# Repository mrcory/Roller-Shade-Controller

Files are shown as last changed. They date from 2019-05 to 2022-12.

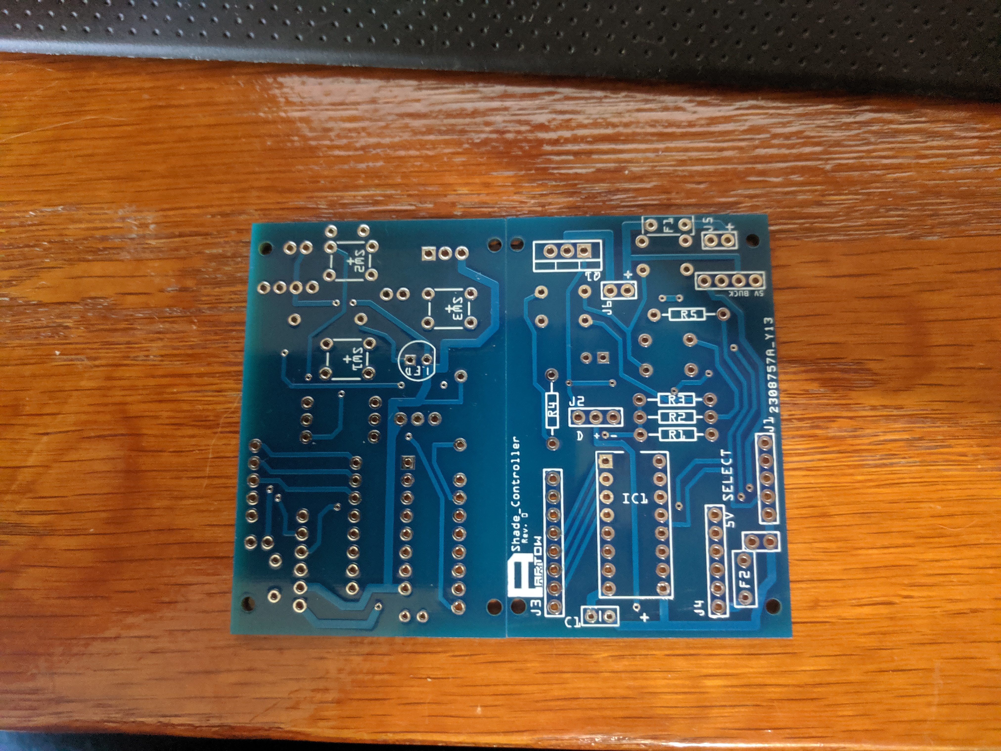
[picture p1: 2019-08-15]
Extra_Resources/Part Images/IMG_20190808_134944.jpg

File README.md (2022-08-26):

# Roller-Shade-Controller
D1 Mini powered roller shade controller for my 3D printed roller shade.

Intended for use with a custom PCB I designed, but can also be used with a custome protoboard. (As I did during testing.)

## Welcome to my little project!
The purpose behind this project was two-fold. One, I want a remote controlled shade for my window, but didn't want to spend that much. Two, I wanted a small project to do to break the tedium of my working on my aquarium controller.

I have succeeded in both of those goals. (If I do say so myself.) I managed to build the majority of the hardware for the shade for under $20 unit cost estimated. (I did luck out on cheap motors) and Unfortunately, this does not include beautification. Function on the other hand has been a success. (Who says you need form with function.)

More features, like physical button control, will add a little bit to the cost but aren't strictly necessary.

## Project Info

## Setup
[Check The Wiki](https://github.com/mrcory/Roller-Shade-Controller/wiki)

### Hardware
 [Thingiverse Models](https://www.thingiverse.com/thing:3628982) are now available.
 
 Motion is driven by a 28BYJ-48 with a ULN2003.

 Currently controlled by a Lolin NodeMCU v3, but it will be replaced by a Wemos D1 Mini

 A donor roller shade.

 1/2" EMT conduit.

### Software
* Blynk is used as a remote control for this project.

* Home Assistant is supported via [home-assistant-integration](https://github.com/dawidchyrzynski/arduino-home-assistant/blob/main/examples/fan/fan.ino).

* [AccelStepper (Fork)](https://github.com/waspinator/AccelStepper) is used to actually drive the motor. _(This version is available in the library manager.)_

* [CmdArduino](https://github.com/fakufaku/CmdArduino) is used for control of serial monitor. (A little library I really like.)

* FastLED is used to control addressable LEDs.  

* WiFiManager as an option to configure WiFi. (>2.7.0)

### Goal
The goal is to make a low cost remote controlled roller shade that can be made DIY. The only tools needed are some hex wrenches, a hacksaw (band saw is also acceptable), and a 3D printer.

More tools may be required to make the final product look nice, but that is _optional_.

## Known Issues
* Due to the way that the stepper is driven Blynk will disconnect when the shade is traveling. This is because Blynk slows the code execution. I believe this is happening due to the time it takes for Blynk to communicate with the server to check for any updates. To make the stepper run smoothly Blynk.run() is not run while the stepper is active by putting it behind an if check.

This issue could be fixed by using an ESP32 in the D1 Mini form factor.

* The code is ugly ~~and lacks comments.~~

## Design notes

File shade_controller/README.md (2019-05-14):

# Roller-Shade-Controller
NodeMCU powered roller shade controller for my 3D printed roller shade.

## Welcome to my little project!
The purpose behind this project was two-fold. One, I want a remote controlled shade for my window, but didn't want to spend that much. Two, I wanted a small project to do to break the tedium of my working on my aquarium controller.

I have succeeded in both of those goals. (If I do say so myself.) I managed to build the majority of the hardware for the shade for under $20 unit cost estimated. (I did luck out on cheap motors) and Unfortunately, this does not include beautification. Function on the other hand has been a success. (Who says you need form with function.)

More features, like physical button control, will add a little bit to the cost but aren't strictly necessary.

## Project Info

### Hardware
 Motion is driven by a 28BYJ-48 with a ULN2003.

 Currently controlled by a Lolin NodeMCU v3, but it will be replaced by a Wemos D1 Mini

 A donor roller shade.

 1/2" EMT conduit.

### Software
Blynk is used as a remote control for this project.

[AccelStepper (Fork)](https://github.com/waspinator/AccelStepper) is used to actually drive the motor. _(This version is available in the library manager.)_

[CmdArduino](https://github.com/fakufaku/CmdArduino) is used for control of serial monitor. (A little library I really like.)

### Goal
The goal is to make a low cost remote controlled roller shade that can be made DIY. The only tools needed are some hex wrenches, a hacksaw (band saw is also acceptable), and a 3D printer.

More tools may be required to make the final product look nice, but that is _optional_.

## Known Issues
* Due to the way that the stepper is driven Blynk will disconnect when the shade is traveling. This is because Blynk slows the code execution. I believe this is happening due to the time it takes for Blynk to communicate with the server to check for any updates. To make the stepper run smoothly Blynk.run() is not run while the stepper is active by putting it behind an if check.

* The code is ugly and lacks comments.

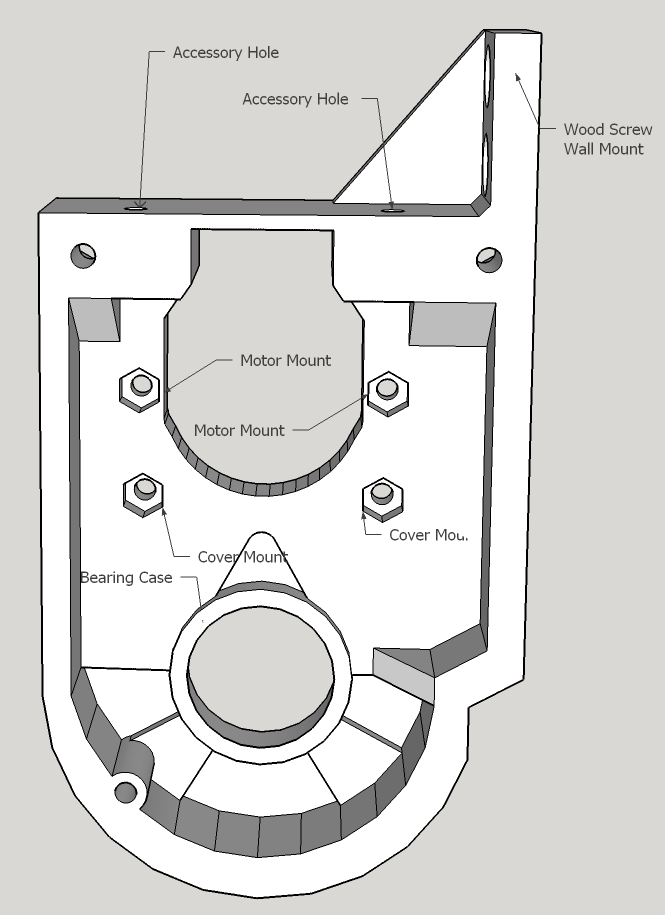
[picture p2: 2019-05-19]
Extra_Resources/Part Images/Body_Acc.png

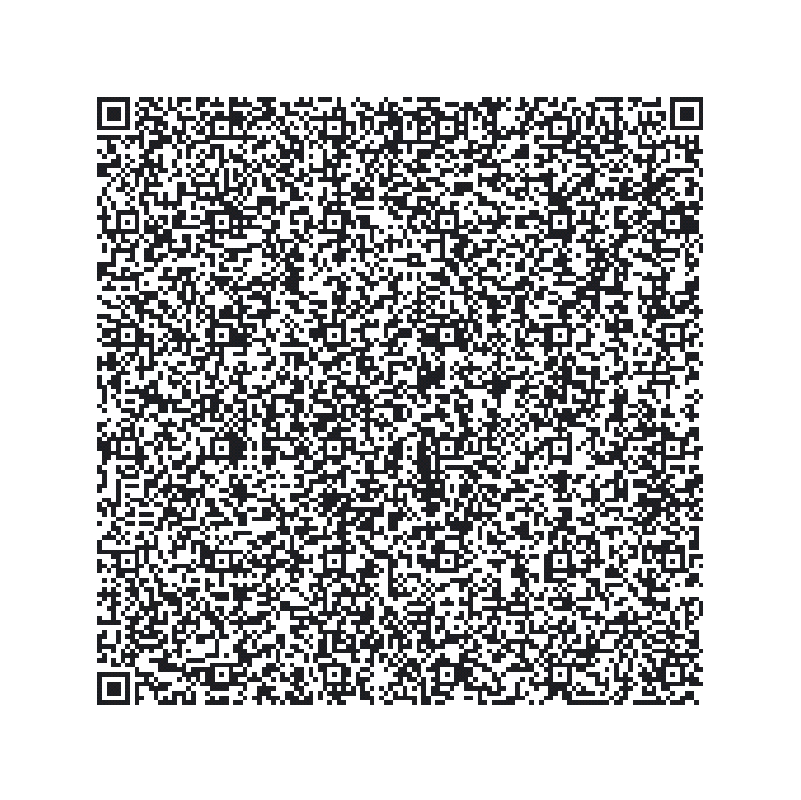
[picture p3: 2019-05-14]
shade_controller/blynk_app_qr.png

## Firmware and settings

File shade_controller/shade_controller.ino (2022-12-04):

/*Roller Shade Control
   Created by: Cory McGahee
   Free for non-commercial use only

   Home Assistant Code Based From:
   https://github.com/dawidchyrzynski/arduino-home-assistant/blob/main/examples/fan/fan.ino

   Designed for use with my 3D printed roller shade.
   https://www.thingiverse.com/thing:3628982

   Serial Commands
   move <val> | Absolute move in steps
   pos  <val> | Move to set positions
   rst        | Reset home position to 0
*/

#define BLYNK_PRINT Serial

//Version
#define softVersion "3.1.0"
const int configVersion = 4;
int   safeConfigVersion = 3; //The oldest version of config that can
//be updated from.

#include "structs.h"

bool firstRun = true;
bool resetFlag = false;
bool configLoadFlag = false;
bool configSaveFlag = false;
long currentDistance = 0;

#include <AccelStepper.h>
#include <EEPROM.h>
#include <ESP8266WiFi.h>
//#ifdef Blynkenable
#include <BlynkSimpleEsp8266.h>
//#endif
#include <Ethernet2.h>
#include "config.h"

//ArduinoOTA
#include <ESP8266mDNS.h>
#include <WiFiUdp.h>
#include <ArduinoOTA.h>
#include "ota.h"

//wifiManager
#ifdef wifiManagerEnable
#include <WiFiManager.h>
#include <ESP8266WebServer.h>
#endif

#ifdef HAenable
#include <ArduinoHA.h>
WiFiClient client;
HADevice device;
HAMqtt mqtt(client, device);
#endif

//FastLED Setup
#include <FastLED.h>
FASTLED_USING_NAMESPACE


CRGB leds[NUM_LEDS];


#if cmds //Enable cmdArduino
#include <Cmd.h>
#endif

byte lastPosition = 2; //Storing a starting value

//Configure AccelStepper
#ifdef stepperMini
AccelStepper stepper(ctrlType, mtrPin1, mtrPin2, mtrPin3, mtrPin4);
#endif

#ifdef stepperNema
AccelStepper stepper = AccelStepper(ctrlType, stepPin, dirPin);
#endif

unsigned long lastUp = 0; //Last mqtt push

long int stepPosition = 0;
int connectAttempt = 0;
long int posNow = 0;
bool moving = false; //Flag
bool myReset = false; //Flag
bool setHome = false; //Flag
long int savedPosition = 100;
bool moveUp = false;
int motorPos = 0;
bool goDown = true;

unsigned long ledTimer;
bool ledFeedback = false;
byte ledMode = 0;
bool pulse = false; //Basic effect

bool lightOn = false;
bool lightOld = true;
int currentColor[3] = {255, 255, 255};
int pulseSpeed = 2;

pwmStruct pwm = {
  ledBrightness, //old
  0, //set
  false, //on
  false, //onOld
  0 //out
};

#ifdef Blynkenable
#include "wifi.h"
#endif

#include "functions.h"

#ifdef HAenable
HACover cover(deviceName);
HACover cover(deviceName, HACover::PositionFeature);
HALight led(deviceNameLED, HALight::BrightnessFeature);

void onCoverCommand(HACover::CoverCommand _cmd, HACover* sender) {
  if (_cmd == HACover::CommandOpen) {
    //Serial.println("Command: Open");
    cover.setState(HACover::StateOpen, true);
    motorPos = 1; //Open Shade

  } else if (_cmd == HACover::CommandClose) {
    //Serial.println("Command: Close");
    cover.setState(HACover::StateClosed, true);
    motorPos = 4; //Close Shade

  }else if (_cmd == HACover::CommandStop) {
        //Serial.println("Command: Stop");
        cover.setState(HACover::StateStopped);
  }
}

void onStateChangeLED(bool _state, HALight* s) {
  if (lightMode == 0) {
    pwm.on = _state;
  }
}

void onBrightnessCommand(uint8_t led_brightness, HALight* sender) {
  pwm.set = led_brightness;
  sender->setBrightness(led_brightness);
}


#endif

#if buttonEnable //Enable physical buttons

#include <AnalogButtons.h>

//Here we are setting up the fuctions that will be called via the physical buttons.
void upClick() {
  Serial.println("Up Click");
  if (lastPosition > 1) {
    lastPosition--;
    motorPos = lastPosition;
    Serial.println(motorPos);
    ledTurn(0);
  } else {
    ledTurn(2);
  }
}

void upHold() {
  Serial.println("Up Hold");
  motorPos = 1;
  lastPosition = 1;
  ledTurn(1);
}

void downClick() {
  Serial.println("Dn Click");
  if (lastPosition < 4) {
    lastPosition++;
    motorPos = lastPosition;
    Serial.println(motorPos);
    ledTurn(0);
  } else {
    ledTurn(2);
  }
}

void downHold() {
  Serial.println("Dn Hold");
  motorPos = 4;
  lastPosition = 4;
  ledTurn(1);
}

void resetClick() {
  Serial.println("Rst Click");

  if (lightMode == 1) {
    lightOn = !lightOn;
    ledBrightness = ledButtonBrightness;
  }

  if (lightMode == 0) {
    pwm.on = !pwm.on;
    pwm.set = ledButtonBrightness;
  }

  ledTurn(1);
}

void resetHold() {
  Serial.println("Rst Hold");
  stepper.setCurrentPosition(0);
  configSave();
  ledTurn(1);
}

//Create tha actual buttons
AnalogButtons buttons(buttonPin, INPUT, buttonDebounce, buttonMargin);
Button up = Button(upVal, &upClick, &upHold, 1000, 5000);
Button down = Button(dnVal, &downClick, &downHold, 1000, 5000);
Button rst = Button(rsVal, &resetClick, &resetHold, 2500, 5000);

#endif

#ifdef Blynkenable
#if rtcBlynk //Enable the RTC feature from Blynk
//Blynk RTC
#include <WidgetRTC.h>
WidgetRTC RTC;
BlynkTimer timer1;
#endif
#endif

#include "lightcontrol.h"

void setup() {
  Serial.begin(74880);
  delay(50);

#ifdef HAenable
  WiFi.begin();
  WiFi.macAddress(mac);
  device.setUniqueId(mac, sizeof(mac));
#endif


#ifdef wifiManagerEnable
  // WiFiManager intialization.
  WiFiManager wifi;
#endif


  analogWrite(PWM_PIN, 0);

  if (lightMode == 1) { //Use FastLED if selected
    FastLED.addLeds<LED_TYPE, DATA_PIN, COLOR_ORDER>(leds, NUM_LEDS);
  }

  pinMode(ledPin, OUTPUT);
  digitalWrite(ledPin, LOW);

#if buttonEnable
  buttons.add(up);
  buttons.add(down);
  buttons.add(rst);
#endif

#if cmds //Define our serial commands if enabled
  cmdInit(&Serial);
  cmdAdd("move", manualMove);
  cmdAdd("rst", homePos);
  cmdAdd("pos", pos);
#endif

#ifdef wifiManagerEnable
  // Create AP, if necessary
  wifi.autoConnect(myHostName);

  // Set WIFI module to STA mode
  WiFi.mode( WIFI_STA );
#endif


#ifdef Blynkenable
  blynkConfig();
#endif
  setupOTA();

  EEPROM.begin(eepromSize); //Initialize the EEPROM with our selected size

  if (EEPROM.read(0) == 1 && returnConfigVersion() >= safeConfigVersion) { //If flagged in EEPROM; we load our current position
    configLoad();
    Serial.println("Pass Config Version Check");
  } else {
    Serial.println("Fail Config Version Check, Reseting To Default");
    configSave();

  }


#ifdef HAenable
  device.setName(deviceName);
  device.setSoftwareVersion(softVersion);

  //Configure LED
  led.setName(deviceNameLED);
  led.setIcon("mdi:lightbulb");

  //LED callback setup
  led.onStateCommand(onStateChangeLED);
  led.onBrightnessCommand(onBrightnessCommand);

  cover.onCommand(onCoverCommand);
  mqtt.begin(brokerAddress, brokerUser, brokerPass);


/*
  if (lastPosition > 1) { //If down, set state as such.
    cover.setState(HACover::StateClosed, true);
  } else { //Else set as open
    cover.setState(HACover::StateOpen, true);
  }
*/

#endif

#ifdef Blynkenable
#if rtcBlynk
  //Using Blynk to get the time
  RTC.begin();
  setSyncInterval(blynkRtcInterval);
#endif
#endif

  stepper.setMaxSpeed(mSpeed.up);
  stepper.setAcceleration(mSpeed.accel);

  stepper.setCurrentPosition(savedPosition);

  motorOff();



  Serial.print(F("Loaded | Position S|C : ")); Serial.print(savedPosition); Serial.print("|"); Serial.println(stepper.currentPosition());
  if (lightMode == 1) { //Use FastLED if selected
    FastLED.setBrightness(ledBrightness);
  }

} //END SETUP


void loop() {
#ifdef HAenable
  mqtt.loop();

  if (millis() - lastUp > 3000) { //Send state every 3 seconds
    if (lastPosition > 1) { //If down, set state as such.
      cover.setPosition(0);
    } else { //Else set as open
      cover.setPosition(1);
    }
  }
#endif

  pwm.old = pwm.set;
  currentDistance = stepper.distanceToGo();

  if (ledFeedback == true) {
    ledFeedbackf();
  }

#if cmds
  cmdPoll();
#endif

#if buttonEnable
  buttons.check(); //Check for button presses
#endif


  //If not moving, run extra features
  if (stepper.distanceToGo() == 0) {

#ifdef Blynkenable
    blynkRun(); //Only run blynk when the stepper is not active
#endif

    if (setHome == true) {
      resetHold(); //Set current position as home
      setHome = false;
    }

    lightControl();

    if (lightMode == 1) { //Use FastLED if selected
      if (ledBrightness != pwm.old) {
        FastLED.setBrightness(ledBrightness);
      }

      FastLED.show();
    }

    if (lightMode == 0) {
      if (pwm.set != pwm.old) {
        analogWrite(PWM_PIN, pwm.set);
        pwm.old = pwm.set;
      }
    }
  }

#ifdef stepperNema
  brakeCheck();
#endif

  stepper.run(); //AccelStepper runs here
  motorControl();
  ArduinoOTA.handle();

  if (resetFlag == true) {
    ESP.reset();
  }

  if (configLoadFlag == true) {
    configLoad();
    configLoadFlag = false;
  }

  if (configSaveFlag == true) {
    configSave();
    configSaveFlag = false;
  }

} //END LOOP

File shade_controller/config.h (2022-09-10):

//Config stuff

//Friendly Name
#define deviceName "Roller_Shade"
#define deviceNameLED "Roller_Shade_LED"

//Uncomment to enable wifi manager
#define wifiManagerEnable

//Enable Blynk (Old Version)
#define Blynkenable
#define rtcBlynk false

//Enable Home Assistant Integration (Displays as a fan)
//Only Supports the shade and not light control
#define HAenable

// Unique ID must be set!
byte mac[] = {0x13, 0x10, 0xFA, 0x6E, 0x38, 0x4A};

//Home Assistant Config
#define brokerAddress IPAddress(192,168,254,84)  //MQTT Broker Address
#define brokerUser "user"                        //Broker Username
#define brokerPass "password"                    //Broker Password

/* Speed Settings in Steps/Second
 * You will have to play with these values to find a 
 * reliable setup. I recomend putting a small extra load
 * (lightly pressing a finger against the roller) to 
 * be sure that there is enough strength to lift the shade
 * reliably.
 * 
 * .! This is used for both motor types !.
 */
 
motorSpeedStruct mSpeed = {
  800, //Up Speed
  1000, //Down Speed
  150   //Acceleration
};



/* Drive motor selection.
 * You have choice between 2 style motors. 
 * 
 * 28BYJ-48 : 5v or 12v | Though slow, these motors are cheap.
 * The 5v has the advantage of being able to receive power from a
 * power bank. This could allow operation when your electricity goes out.
 * 
 * Nema 17 : 12v        | This motor should be faster, but will require a
 * brake or to remain powered to hold its position.
 * 
 * 28BYJ will be controlled by steps, while Nema will be controlled by degrees.
 * 
 * Uncomment the appropriate line below. Edit the config at the top of selected.
 */
#include "stepperMini.h"
//#include "stepperNema.h"

int connectTimeout = 100;      // How many attempts can we make before giving up on Blynk
//#define blynkRtcInterval = 30; // How often to sync the time. (Would be used for timers)

#ifdef Blynkenable
  #include "blynk.h" //Contains Blynk login
#endif

//------Timer
int stepperPos[] = {0,6000};
int stepperTime[2][2] = {};
//------Not currently used

/* Set size for the eeprom.
 * 512 is way more than will be needed.
 * All that is being stored there is position data
 * after each move is completed.
 */
const int eepromSize = 512;



//Button Config
#define buttonEnable true //True to enable button controls
#define buttonPin A0      //Analog pin for buttons

//AnalogRead values for buttons
#define upVal 895
#define dnVal 980
#define rsVal 1024

/*  The margin that analogButtons uses to determine
 *  if a button has been pressed. Default is 20, but
 *  I use 30. As long as there is plenty of gap between 
 *  values set above, this can be set larger.
 */
#define buttonMargin 30
#define buttonDebounce 3 //Debounce for buttons. Lower causes faster trigger.
#define ANALOGBUTTONS_SAMPLING_INTERVAL 10

//Feedback for button presses
#define ledPin D3        //Feedback LED

/*  This will allow control of an accessory light via
 *  PWM or FastLED.
 *  If using FastLED controlled lights, be careful of
 *  the number you use. Always calcualte the max possible
 *  power consumption and add a safety margin.
 */
#define alternateFunction false //Enable alternate use of the reset button
#define lightMode 0             //0-PWM 1-FastLED

/*  Light accessory settings (Not the feedback LED)
 *  Using FastLED to run some WS2812 
 *  The data pin for the WS2812 is set in the main ino 
 *  around line 31
*/
int ledBrightness = 900;        //Starting brightness
int ledButtonBrightness = 50; //Brightness to use when using rst button to turn on light.
int pulseMax = 250;           //Max brightness for pulse mode. Max 250 or it will loop to near 0
                              //Can be set in Blynk

//FastLED Settings
#define NUM_LEDS 9         //Number of attached LEDs
#define DATA_PIN    D2     //Communication pin for the LEDs | Same pin will be used for either LED control
#define LED_TYPE    WS2812 //LED controller
#define COLOR_ORDER GRB    //Order to send colors

//PWM Light Settings
#define PWM_PIN     D2     //Rev.0 PCB uses D2


//Extra Stuff
#define cmds true //After setting up positions, cmdArduino can be disabled

//OTA Settings
#define updatePassword "admin"
#define myHostName     "Shade"

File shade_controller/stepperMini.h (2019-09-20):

//Code for 28BYJ-48
#define stepperMini


/* Config Section
 *  
 */

/* Set positions 1-4 in steps for stop locations. 
 * Scaled is figured for 10 positions between 1 and 4
 * Position:     1    2     3     4   Scaled
 */
long shade[5] = {0,20500,41000,60000,0};

//Declare motor pins
#define mtrPin1 D5//D5
#define mtrPin2 D7//D7
#define mtrPin3 D6//D6
#define mtrPin4 D8//D8

const int stepPerRev = 4096; //Steps needed to make 1 revolution

#define ctrlType 8 //HalfStep


/* Motor Specific Functions
 *  
 */

//Write motor pins low to be sure the motor is unpowered
void motorOff() {
  digitalWrite(mtrPin1,LOW);
  digitalWrite(mtrPin2,LOW);
  digitalWrite(mtrPin3,LOW);
  digitalWrite(mtrPin4,LOW);
  
}

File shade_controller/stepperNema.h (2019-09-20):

//Code for Nema 17

#define stepperNema

/* Config Section
 *  
 */

/* Set positions 1-4 in steps for stop locations. 
 * Scaled is figured for 10 positions between 1 and 4
 * Position:     1    2     3     4   Scaled
 */
long shade[5] = {0,5,10,20,0};

#define dirPin    1  //Direction control pin
#define stepPin   2  //Step control pin
#define ctrlType  1  //Control type for accelstepper
#define enablePin 11 //Pin to enable/disable motor
#define brakePin  10 //Pin used to control the brake

//Variables
bool brakeOn = true;



//Funtions
void motorOff() {
    if (brakeOn == false) {
      digitalWrite(brakePin,LOW);
      brakeOn = true;
      digitalWrite(enablePin,HIGH);
      delay(100); //Actuation time
    }
}

void brakeCheck() {
  if (currentDistance != 0 && brakeOn == true) {
      digitalWrite(enablePin,LOW);
      digitalWrite(brakePin,HIGH);
      brakeOn = false;
      delay(100); //Actuation time
  }
}

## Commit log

2019-05-14 Move pin config to proper place.
2019-05-14 My Current Blynk App
2019-05-15 Added button support
    Now supports 3 buttons via analogButtons.
    1. Up: Click and hold
    2.Down: Click and hold
    3. Reset Position: Click
    [config.h, shade_controller.ino]
2019-05-15 LED Feedback added.
    An LED can now be attached to act as feedback for pressing buttons.
2019-05-15 Reset now requires hold instead of click.
    [shade_controller.ino]
2019-05-16 Added another LED status effect.
    It is supposed to be a double flash, but acts weirdly. Not to worried about that at the moment as it still provides a different effect.
    Used when you press up or down and are already at the max.
2019-05-17 Fix LED double flash flicker
2019-05-21 Light can be turned on via RST button
    To turn on the light hold the rst button for 250-500ms, to reset position hold for 2.5+ seconds
    [config.h, shade_controller.ino]
2019-05-24 Move settings to config.
    Added ability to set button debounce in config
2019-08-04 Prep for LED strip support.
2019-08-15 Add PWM light conrols
2019-08-15 PWM light additions
2020-02-14 Update config save/load and add motor inversion code
2020-02-14 New config system
    Added versioning to prevent loading an incompatible config from EEPROM
    [shade_controller.ino]
2020-02-14 Added forgotten brackets
2020-02-14 Added config version checking
    Checks that the saved config info is compatible with the current setup.
2020-02-14 PWM Light now remembers the previous brightness
2020-02-14 Added invert function to loop
    [shade_controller.ino]
2020-02-14 Added timer for Blynk.run()
    Imported the timer code I use in my aquirium controller.
2020-02-14 Sync device values with app
2020-02-14 Removed reset and added config save button
    [shade_controller.ino]
2020-02-14 Decrase button lag
2020-02-14 Sync led power and brightness with app
2020-02-14 Add ArduinoOTA
2020-02-16 MAJOR REVERT
    At an unknown time I broke the eeprom functions. Restarting before resent changes.
    [config.h, shade_controller.ino, stepperMini.h]
2020-02-17 Fix PWM led
2020-02-17 Hardware button brightness can now be set in the app.
2020-02-17 Fix light power button
    Light can be turned off while preserving brightness.
    [shade_controller.ino]
2020-02-22 Added Gerber File
    Reference Gerber files for the Rev.3 board. This board is for use with the mini stepper.
2020-03-02 Add PCB Files
    [shade_rev3_contour.gm1, shade_rev3_copperBottom.gbl, shade_rev3_copperTop.gtl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]
2020-03-02 Remove bad pcb files
2020-03-04 Shade now restarts when inverting
    Changing the inversion setting wasn't applying until restarting, so now a restart is called when changing the setting.
    [shade_controller.ino]
2022-09-10 Added LED control with Home Assistant
    LED (PWM) can now be controlled with Home Assistant. Set desired brightness in the config.
